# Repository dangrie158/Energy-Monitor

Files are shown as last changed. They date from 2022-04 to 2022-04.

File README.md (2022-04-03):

# Energy Monitor

A simple 6-channel  energy monitor for the whole house.
Uses 0-5V Current Transducers for current measureent and has a build-in voltage transformer for voltage measurement.
Brains are a Raspberry Pi Zero due to low cost and easy integration into the home WiFi and inclusion with MQTT or any other protocol to include the measurements in all kinds of home automation systems.

## Example Configuration

Channels 1, 2, 3 on L1, L2, L3 -> whole house consumption
Channels 4, 5, 6 on different room connections / devices

## Known Limitations

The Voltage is only measured on a single phase and thus only apperant power can be measured on the channels that connect to a different phase than the supply phase

## Licence

<p xmlns:dct="http://purl.org/dc/terms/" xmlns:vcard="http://www.w3.org/2001/vcard-rdf/3.0#">
  <a rel="license"
     href="http://creativecommons.org/publicdomain/zero/1.0/">
    
  </a>
</p>

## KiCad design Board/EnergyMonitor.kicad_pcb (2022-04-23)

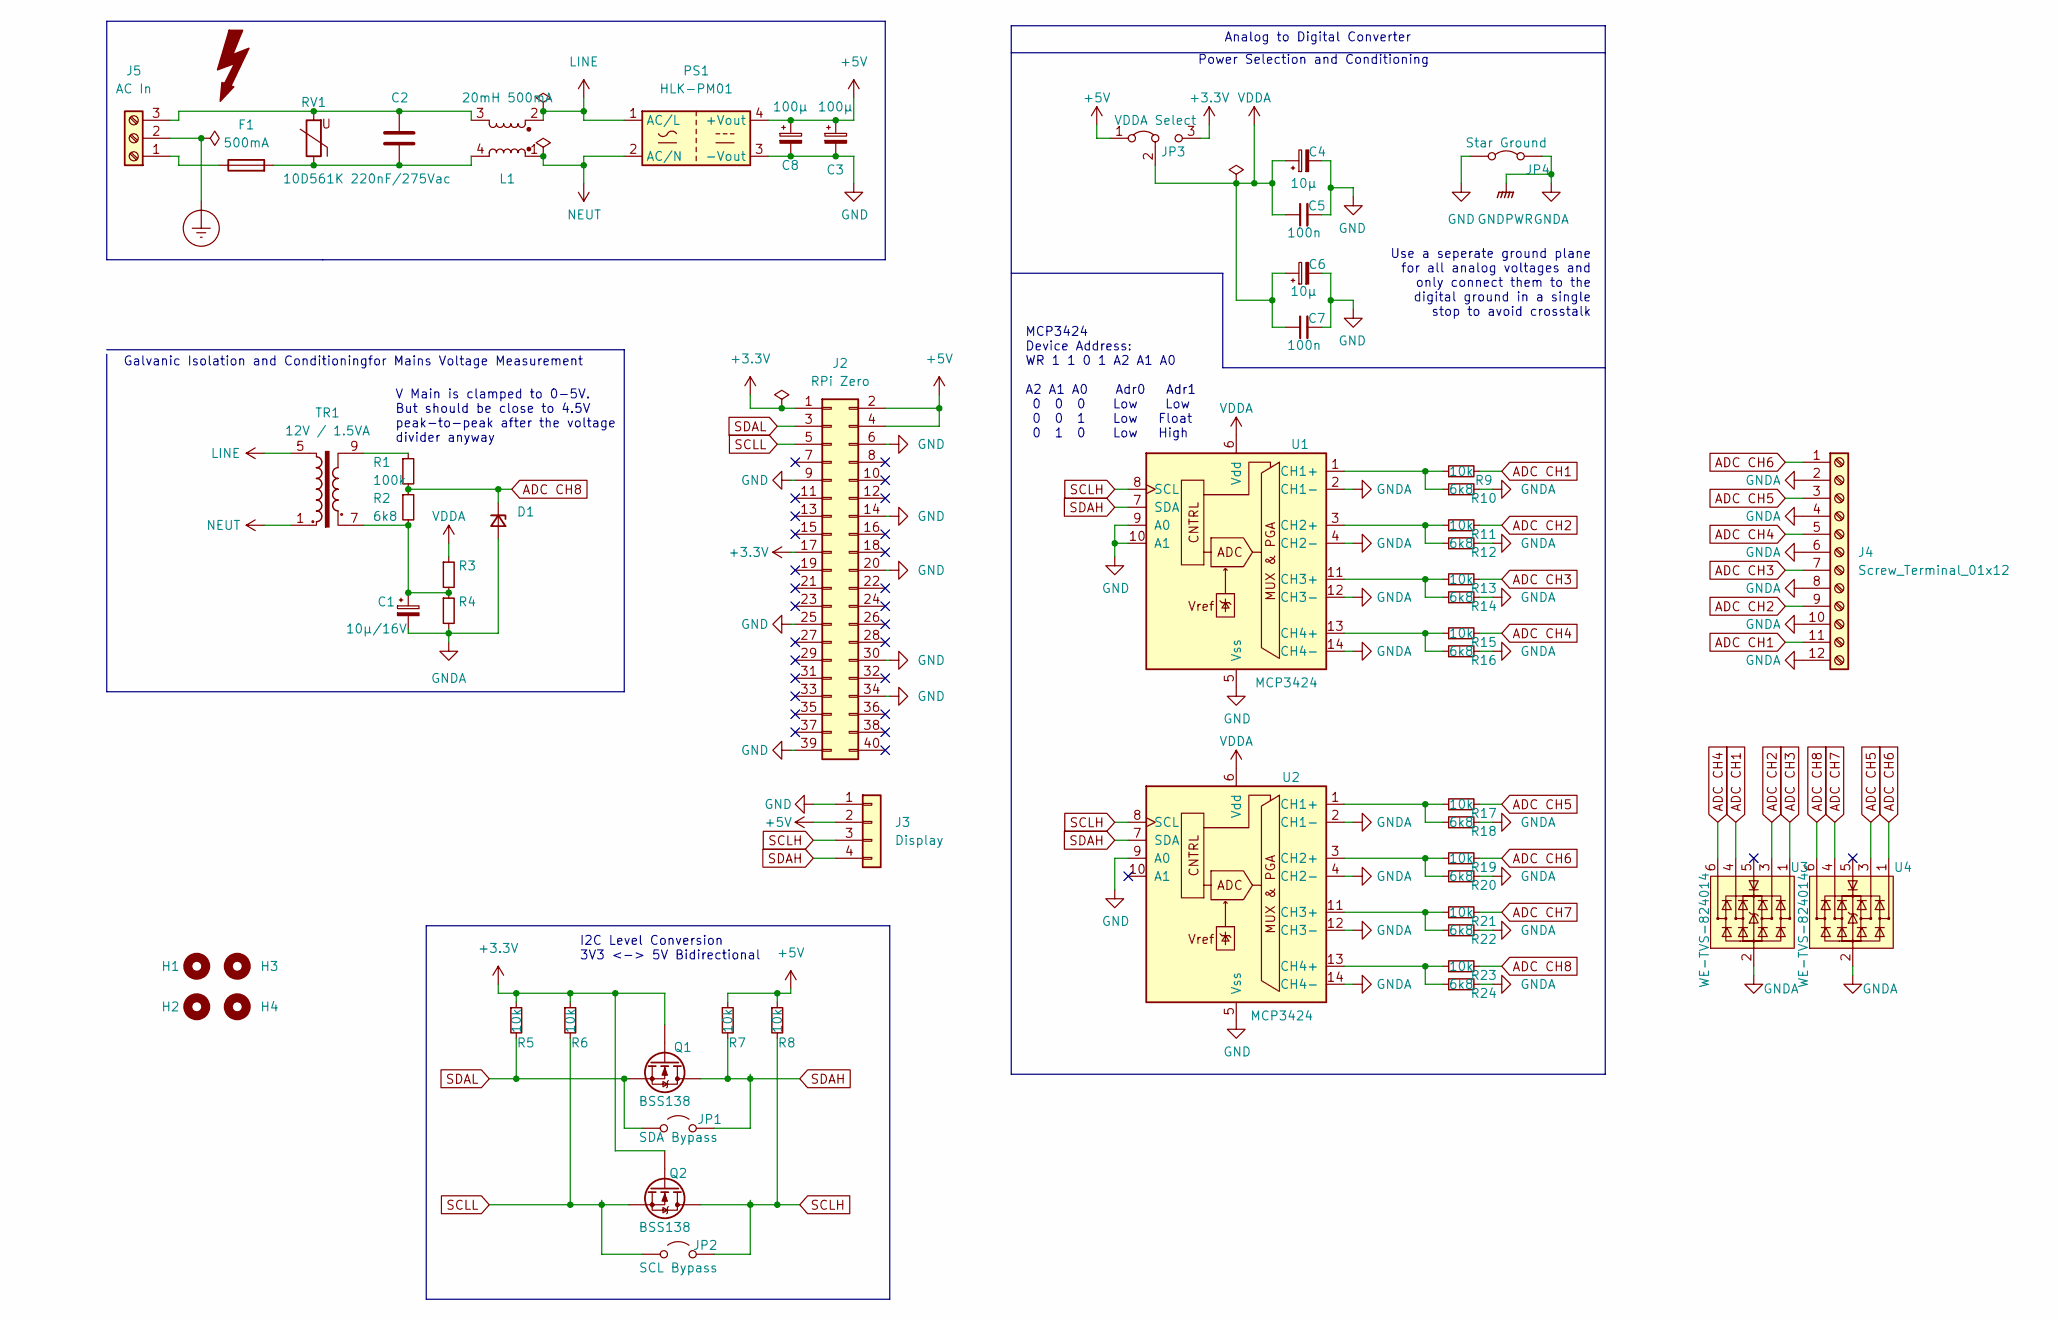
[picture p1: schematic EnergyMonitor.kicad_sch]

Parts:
C1: 10µ/16V; CP_EIA-3216-18_Kemet-A_Pad1.58x1.35mm_HandSolder
C2: 220nF/275Vac; C_Rect_L13.0mm_W6.0mm_P10.00mm_FKS3_FKP3_MKS4
C3, C8: 100µ; CP_Elec_5x5.4
C4, C6: 10µ; CP_EIA-3216-18_Kemet-A_Pad1.58x1.35mm_HandSolder
C5, C7: 100n; C_0603_1608Metric_Pad1.08x0.95mm_HandSolder
D1: D_MiniMELF_Handsoldering
F1: 500mA; Fuseholder_Cylinder-5x20mm_Schurter_0031_8201_Horizontal_Op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
H1, H2, H3, H4: MountingHole; MountingHole_2.7mm_M2.5_DIN965
J2: RPi Zero; Raspberry Pi Zero
J3: Display; JST_XH_B4B-XH-AM_1x04_P2.50mm_Vertical
J4: Screw_Terminal_01x12; TerminalBlock_Phoenix_PT-1,5-12-5.0-H_1x12_P5.00mm_Horizont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
J5: AC In; TerminalBlock_MetzConnect_Type175_RT02703HBLC_1x03_P7.50mm_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
JP1: SDA Bypass; SolderJumper-2_P1.3mm_Open_RoundedPad1.0x1.5mm
JP2: SCL Bypass; SolderJumper-2_P1.3mm_Open_RoundedPad1.0x1.5mm
JP3: VDDA Select; SolderJumper-3_P1.3mm_Bridged12_RoundedPad1.0x1.5mm
JP4: Star Ground; SolderJumper-2_P1.3mm_Bridged2Bar_RoundedPad1.0x1.5mm
L1: 20mH 500mA; UU9.8
PS1: HLK-PM01; Converter_ACDC_HiLink_HLK-PMxx
Q1, Q2: BSS138; SOT-23
R1: 100k; R_1206_3216Metric_Pad1.30x1.75mm_HandSolder
R2: 6k8; R_1206_3216Metric_Pad1.30x1.75mm_HandSolder
R3, R4: R_1206_3216Metric_Pad1.30x1.75mm_HandSolder
R5, R6, R7, R8, R9, R11, R13, R15, R17, R19, R21, R23: 10k; R_0603_1608Metric_Pad0.98x0.95mm_HandSolder
R10, R12, R14, R16, R18, R20, R22, R24: 6k8; R_0603_1608Metric_Pad0.98x0.95mm_HandSolder
RV1: 10D561K; RV_Disc_D12mm_W5.4mm_P7.5mm
TR1: 12V / 1.5VA; BV EL 30
U1, U2: MCP3424; SO-14_3.9x8.65mm_P1.27mm
U3, U4: WE-TVS-824014; SOT-23-6

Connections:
+3V3: J2.1, J2.17, JP3.3 (B), Q1.1 (G), Q2.1 (G), R5.1, R6.1
+5V: C3.1, C8.1, J2.2, J2.4, J3.2, JP3.1 (A), PS1.4 (+Vout), R7.1, R8.1
ADC CH1: J4.11, R9.2, U3.4
ADC CH2: J4.9, R11.2, U3.3
ADC CH3: J4.7, R13.2, U3.1
ADC CH4: J4.5, R15.2, U3.6
ADC CH5: J4.3, R17.2, U4.3
ADC CH6: J4.1, R19.2, U4.1
ADC CH7: R21.2, U4.4
ADC CH8: D1.1 (K), R1.2, R2.1, R23.2, U4.6
Earth_Protective: J5.2
GND: C3.2, C4.2, C5.2, C6.2, C7.2, C8.2, J2.6, J2.9, J2.14, J2.20, J2.25, J2.30, J2.34, J2.39, J3.1, JP4.1 (A), PS1.3 (-Vout), U1.5 (Vss), U1.9 (A0), U1.10 (A1), U2.5 (Vss), U2.9 (A0)
GNDA: C1.2, D1.2 (A), J4.2, J4.4, J4.6, J4.8, J4.10, J4.12, JP4.2 (B), R4.2, R10.2, R12.2, R14.2, R16.2, R18.2, R20.2, R22.2, R24.2, U1.2 (CH1-), U1.4 (CH2-), U1.12 (CH3-), U1.14 (CH4-), U2.2 (CH1-), U2.4 (CH2-), U2.12 (CH3-), U2.14 (CH4-), U3.2, U4.2
LINE: L1.2, PS1.1 (AC/L), TR1.5
NEUT: L1.1, PS1.2 (AC/N), TR1.1
unnamed: C1.1, R2.2, R3.2, R4.1, TR1.7
unnamed: C2.1, J5.3, L1.3, RV1.2
unnamed: C2.2, F1.2, L1.4, RV1.1
unnamed: F1.1, J5.1
unnamed: R1.1, TR1.9
unnamed: R9.1, R10.1, U1.1 (CH1+)
unnamed: R11.1, R12.1, U1.3 (CH2+)
unnamed: R13.1, R14.1, U1.11 (CH3+)
unnamed: R15.1, R16.1, U1.13 (CH4+)
unnamed: R17.1, R18.1, U2.1 (CH1+)
unnamed: R19.1, R20.1, U2.3 (CH2+)
unnamed: R21.1, R22.1, U2.11 (CH3+)
unnamed: R23.1, R24.1, U2.13 (CH4+)
SCLH: J3.3, JP2.2 (B), Q2.3 (D), R8.2, U1.8 (SCL), U2.8 (SCL)
SCLL: J2.5, JP2.1 (A), Q2.2 (S), R6.2
SDAH: J3.4, JP1.2 (B), Q1.3 (D), R7.2, U1.7 (SDA), U2.7 (SDA)
SDAL: J2.3, JP1.1 (A), Q1.2 (S), R5.2
VDDA: C4.1, C5.1, C6.1, C7.1, JP3.2 (C), R3.1, U1.6 (Vdd), U2.6 (Vdd)

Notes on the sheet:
Use a seperate ground plane for all analog voltages and only connect them to the digital ground in a single stop to avoid crosstalk
MCP3424 Device Address: WR 1 1 0 1 A2 A1 A0 A2 A1 A0 Adr0 Adr1 0 0 0 Low Low 0 0 1 Low Float 0 1 0 Low High
Galvanic Isolation and Conditioningfor Mains Voltage Measurement
V Main is clamped to 0-5V. But should be close to 4.5V peak-to-peak after the voltage divider anyway
Power Selection and Conditioning
Analog to Digital Converter
I2C Level Conversion 3V3 <-> 5V Bidirectional

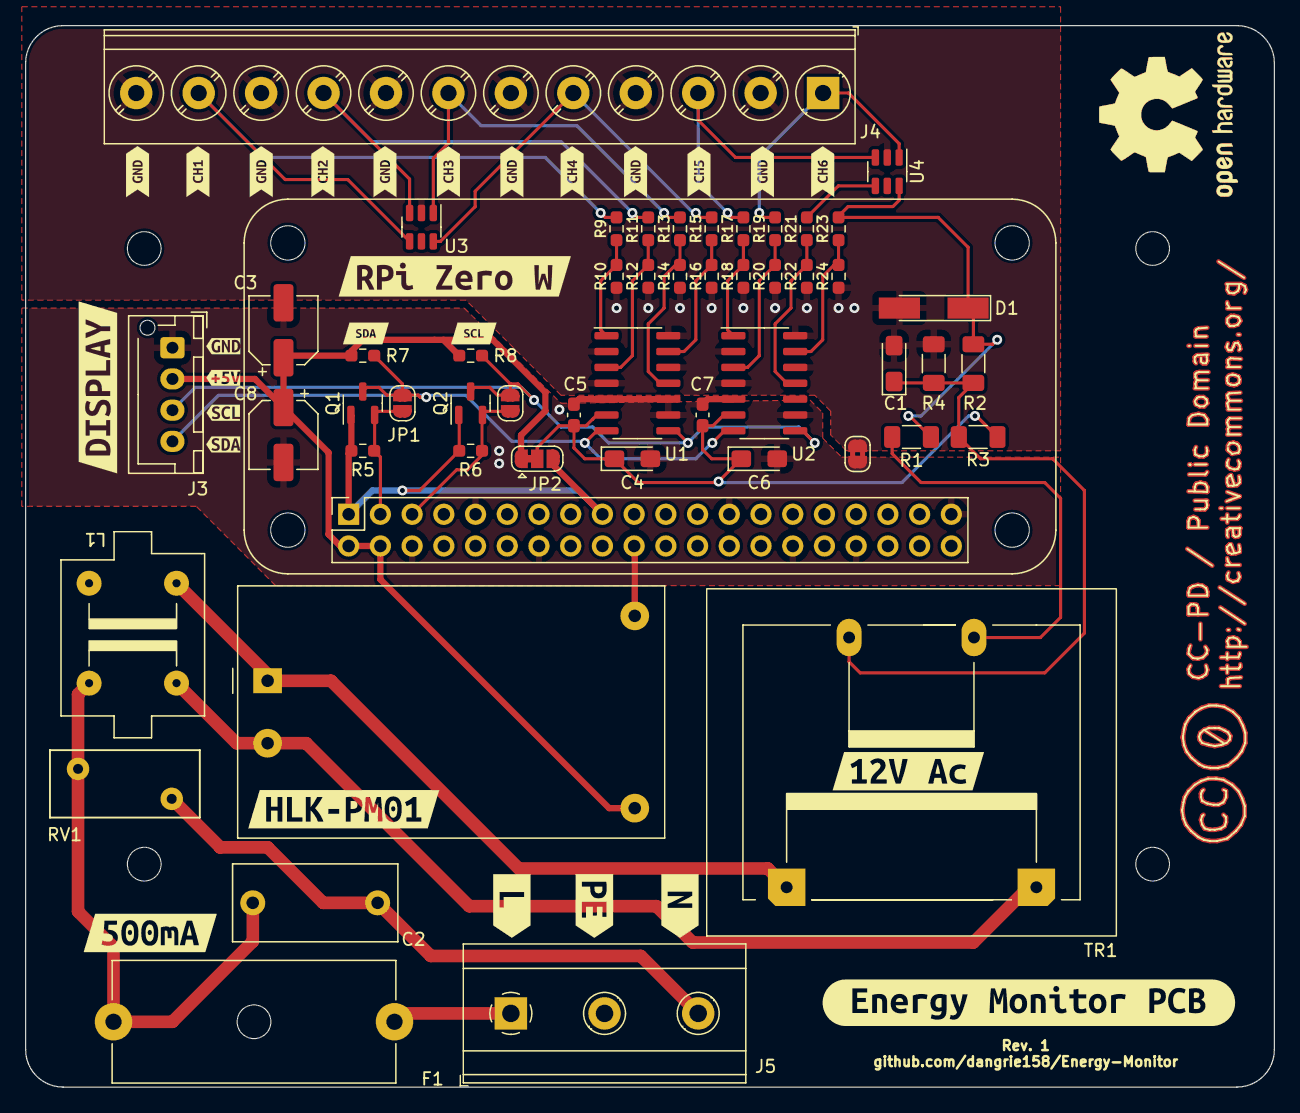
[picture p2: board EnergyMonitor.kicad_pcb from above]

Board: 2 copper layers, 100.0 x 85.0 mm, 83 parts (0 on the bottom side), 32 nets.

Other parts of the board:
kibuzzard-6249A75F: G***; kibuzzard-6249A75F
kibuzzard-6249A77E: G***; kibuzzard-6249A77E
kibuzzard-6249A574: G***; kibuzzard-6249A574
kibuzzard-6249A738: G***; kibuzzard-6249A738
kibuzzard-6249A748: G***; kibuzzard-6249A748
kibuzzard-6249A773: G***; kibuzzard-6249A773
kibuzzard-6249A788: G***; kibuzzard-6249A788
kibuzzard-6249A794, kibuzzard-6249A794#2, kibuzzard-6249A794#3, kibuzzard-6249A794#4, kibuzzard-6249A794#5, kibuzzard-6249A794#6: G***; kibuzzard-6249A794
kibuzzard-6249ABCA: G***; kibuzzard-6249ABCA
kibuzzard-6249B42C: G***; kibuzzard-6249B42C
kibuzzard-6249B43B: G***; kibuzzard-6249B43B
kibuzzard-6249B420: G***; kibuzzard-6249B420
kibuzzard-6249B447: G***; kibuzzard-6249B447
kibuzzard-624990CE: G***; kibuzzard-624990CE
kibuzzard-624991A3: G***; kibuzzard-624991A3
kibuzzard-624991BE: G***; kibuzzard-624991BE
kibuzzard-624992C2: G***; kibuzzard-624992C2
kibuzzard-624992EE: G***; kibuzzard-624992EE
kibuzzard-6249901A: G***; kibuzzard-6249901A
kibuzzard-62499035: G***; kibuzzard-62499035
kibuzzard-62499525: G***; kibuzzard-62499525
kibuzzard-62499532: G***; kibuzzard-62499532

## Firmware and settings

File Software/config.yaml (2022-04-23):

mqtt:
  host: grafana.local
  port: 1883
  messages:
    - topic: "energymeter"
      payload: "{unit},channel={name} value={value}"
    - topic: "energymeter/{name}"
      payload: "{value}"

# time in seconds between reads of each channel.
sample_every: 5
adc_addresses:
  - 0x68
  - 0x69
display_address: 0x3C

channels:
  - name: L1
    channel: 1
    bits: 16
    samples: 3 #at 18 bits we can sample with ~3 samples/s
    aggregator: average
    calibration_points:
      - [0, 0]
      - [4307, 9.31]
    unit: A
    type: current_phase

  - name: L2
    channel: 2
    bits: 16
    samples: 3
    aggregator: average
    calibration_points:
      - [0, 0]
      - [4307, 9.31]
    unit: A
    type: current_phase

  - name: L3
    channel: 3
    bits: 16
    samples: 3
    aggregator: average
    calibration_points:
      - [0, 0]
      - [4307, 9.31]
    unit: A
    type: current_phase

  - name: VRms
    channel: 8
    bits: 12 # with 14 bits we should get 60 samples/s so we avoid always samling at the same time at 50 hZ
    samples: 240 # collect samples for 1 second to calculate rms voltage
    aggregator: rms
    calibration_points:
      - [52, 0] # slight offset as a measurment artifact
      - [400, 330]
    unit: V
    type: voltage


  - name: Wohnzimmer
    channel: 4
    bits: 16
    samples: 3
    aggregator: average
    calibration_points:
      - [0, 0]
      - [4307, 9.31]
    unit: A
    type: current_other

  - name: Durchlauferhitzer
    channel: 5
    bits: 16
    samples: 3
    aggregator: average
    calibration_points:
      - [-50, 0]
      - [2153, 9.31]
    unit: A
    type: current_other

displays:
  - title: Verlauf heute
    type: PowerHistory
    num_bins: 24
    display_time: 5

  - title: Netzspannung
    type: CurrentVoltage
    display_time: 5

  - title: Energieverbrauch
    type: CurrentPower
    display_time: 10

  - title: Verbrauch heute
    type: DailyPower
    display_time: 10

  - title: Warmwasser
    type: PowerHistory
    num_bins: 24
    display_time: 5
    channel_name: Durchlauferhitzer

  - title: Warmwasser
    type: DailyPower
    display_time: 5
    channel_name: Durchlauferhitzer

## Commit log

2022-04-02 initial board commit
    [EnergyMonitor.kicad_pcb, EnergyMonitor.kicad_sch]
2022-04-03 fully routed pcb
    [EnergyMonitor.kicad_pcb, EnergyMonitor.kicad_sch]
2022-04-04 resized PCB slightly for a better fit in the case
    [EnergyMonitor.kicad_pcb, EnergyMonitor.kicad_sch]
2022-04-04 added 3d step file of the board
2022-04-04 added gerbers from first pcb order
    [EnergyMonitor-B_Cu.gbl, EnergyMonitor-B_Mask.gbs, EnergyMonitor-B_Paste.gbp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]
2022-04-05 added first draft of acquisition software with dummy adc
2022-04-06 fixed issue in sample aggregations
2022-04-06 fixed mqtt message payload format to use proper telegraf format
    [config.yaml]
2022-04-06 added new daily power history chart type
2022-04-06 added extra current channels to statistics and displays
2022-04-07 added supervision of reader thread to automatically restart if the thread dies
2022-04-14 added first approximation for current measurement
2022-04-14 added live voltage display
2022-04-14 fixed unit error in total live power mqtt message
2022-04-14 added total daily power mqtt message
2022-04-14 switched to watts as base unit for power mqtt messages
2022-04-19 fixed some board layout issues after prototype assembly
    [EnergyMonitor.kicad_pcb, EnergyMonitor.kicad_sch]
2022-04-23 refactored old adc module to respect signbit
2022-04-23 do not populate pull up resistor on Vrms line
    [EnergyMonitor.kicad_sch]
2022-04-23 fixed offset voltage for vrms measurment
    [EnergyMonitor.kicad_sch]
2022-04-23 adjusted configuration after fixing the conversion error
    [config.yaml]
2022-04-23 updated board to match updated schematic
    [EnergyMonitor.kicad_pcb]

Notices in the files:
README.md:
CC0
